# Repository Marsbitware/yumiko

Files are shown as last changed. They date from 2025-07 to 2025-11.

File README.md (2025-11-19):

# Yumiko – Smart AI Camera for Raspberry Pi

Yumiko is an AI-powered camera app for the Raspberry Pi, featuring live preview, AI style transfer, gallery navigation, QR code export, and a fullscreen GUI for touchscreens.  
Designed for Pi 4 with Raspberry Pi Camera v3 and a 3.5" LCD touchscreen.

Yumiko comes from the Japanese yume (夢, “dream”) and -ko (子, “child”), meaning “child of the dream.”
The name reflects the project’s core idea: turning ambitious concepts into a practical and funny tool.

We hope you enjoy using and testing our Project!

<p align="center">
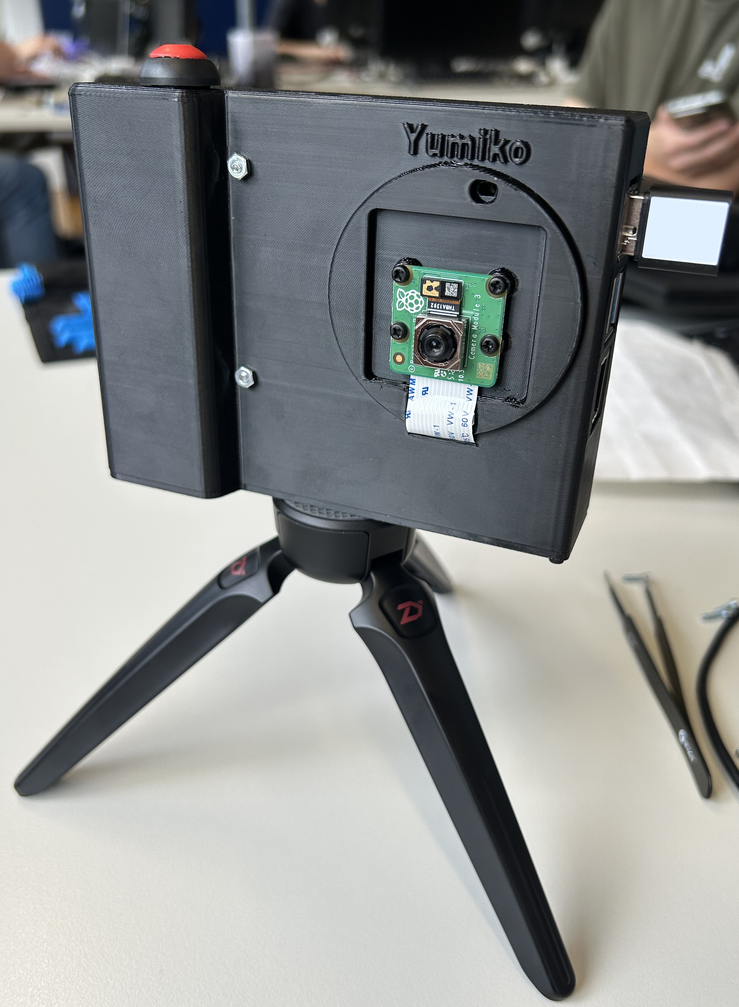
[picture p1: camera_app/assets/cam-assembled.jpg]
Cam assembled
  
</p>

Inspiration:
  - [pi-camera](https://github.com/geerlingguy/pi-camera) by [Jeff Geerling](https://github.com/geerlingguy/)
  - [PIKON Camera](https://www.kevsrobots.com/blog/pikon-camera.html) by [Kevin McAleer](https://www.kevsrobots.com)

---

## Features

- Live camera preview (picamera2)
- AI style transfer (OpenAI API)
- Gallery mode with touch navigation
- Style overlay with GIF loading animation
- QR code for image download
- GPIO button control
- Fullscreen GUI for touchscreens

---

### Directory Structure
```
yumiko/
├── camera_app/
│   ├── camera.py             ← Main application
│   ├── start_camera.sh       ← Start script (for autostart)
│   ├── server.py             ← Start script (for flask-server)
│   ├── assets/
│   │   ├── icons/            ← Gallery, QR, magic wand icons, GIFs, etc.
│   │   ├── styles/           ← Style image buttons
│   │   └── test/             ← Test images or debug material
│   ├── stl_files/            ← stl files for camera case
│   ├── photos/               ← Photos + stylized images
│   └── requirements.txt      ← Python dependencies
├── .gitignore               
├── README.md                 
```

---

## Requirements
- Verified OpenAI account with sufficient funds available and a valid API key
- Raspberry Pi 4 model B (2 GB RAM or better)
- Raspberry Pi Camera v3 (other camera modules should work too)
- 3.5 inch GPIO LCD touchscreen (in our case: Joy-IT model)
- Raspberry Pi OS (Debian Bookworm 64-bit)
- microSD card
- 12mm push button
- 2x4 2.54 mm female headers
- USB-C powerbank and USB-C cable to power the Pi
- Screws and nuts:
    - M2.5 x 12 mm, 4 pcs, each with nut (for Pi)
    - M2.5 x 4 mm screws, 4 pcs (for front camera attachment)
    - M2 x 5 mm screws, 4 pcs (for bottom plate)
- 3D printed case (STL files in the corresponding directory)
- melt-in thread insert: 1/4 Inch 20UNC
- Wireless USB Adapter (in our case: D-Link DWA-131 N300)

---

## 3D-Printed Enclosure

This custom enclosure is based on [Kevin McAleer's](https://www.kevsrobots.com/blog/pikon-camera.html) and [Jeff Geerling’s](https://github.com/geerlingguy/pi-camera) designs and has been modified to better suit the Yumiko build.

### Modifications

Several changes were made to accommodate additional hardware:

- A **12 mm pushbutton** and a **power bank** have been integrated into the case.
- The enclosure was **enlarged along the X and Y axes** to fit the power bank, which slightly exceeds the original dimensions.
- A **reinforced hole** was added to the bottom of the case to support a **melt-in threaded insert** for tripod mounting.
- An additional **access hole** below the battery allows for easy pressing of the power bank’s power button — making Yumiko simple to turn on and off.

### Parts

The enclosure is split into two components:
- `Main_Case.stl`
- `Bottom.stl`

You can find both STL files inside the [`stl_files/`](/camera_app/stl_files) directory.
## Assembly

- Begin by soldering the two leads of the 12mm pushbutton to the first and last pins on one of the 2x4 female headers. (In this setup, one lead connects to a ground pin and the other to GPIO pin 21. Depending on your  configuration, the GPIO pin may vary.)

- Feed the camera module's ribbon cable through the front slit of the enclosure.

- Mount the camera module inside the case using M2.5 x 4mm screws.

- Place the Raspberry Pi into the enclosure so that its ports are aligned with the opening on the left side.

- Secure the Raspberry Pi to the four internal standoffs using M2 x 12mm screws inserted from the outside. Fasten them with nuts on the inside, above the Pi board.

- Connect the ribbon cable from the camera to the Pi’s CSI camera port. Make sure the metal contacts on the ribbon face toward the Pi’s port side.

- Insert the pre-soldered pushbutton header onto the GPIO pins, ensuring that one pin goes to ground and the other to GPIO 21. Carefully bend the wires so they do not press against the display module.

- Attach the Waveshare GPIO TFT display directly onto the Raspberry Pi's GPIO header. It should sit flush on top of the Pi 4 Model B.

- Gently position the camera ribbon cable behind the display to keep everything neat.

- Melt the threaded insert into the bottom plate by using a soldering iron (set to 200–250 °C). Gently heat the insert until it sinks into the hole and fuses with the plastic.

- Finally, secure the bottom cover to the main enclosure using four M2 screws.
---

## Quick Installation

### 1. Flash Raspberry Pi OS

- Use Raspberry Pi Imager to write Raspberry Pi OS 64-bit (Bookworm) to your microSD card.
- Enable SSH and set a username (e.g. `admin`) during flashing.

### 2. First Boot & Basic Setup

```
# Connect via SSH
ssh admin@<IP-address>
```

```
# Update system and install dependencies
sudo apt update
sudo apt install -y python3-pyqt5 python3-opencv libqt5gui5 libqt5widgets5 libqt5core5a libqt5network5 \
    libjpeg-dev libatlas-base-dev git dkms build-essential raspberrypi-kernel-headers hostapd dnsmasq \
    xinput-calibrator
```

### 3. Display Driver

```
git clone https://github.com/goodtft/LCD-show.git
chmod -R 755 LCD-show
cd LCD-show
sudo ./LCD35-show
```
Reboots automatically

To rotate display:
```
cd LCD-show
./rotate.sh 180 #(or 90/270)
```
Also reboots automatically

### 4. Touchscreen Calibration

This step will only be necessary if your touch input is inverted.
```
sudo rm /etc/X11/xorg.conf.d/99-calibration.conf
sudo nano /etc/X11/xorg.conf.d/99-calibration.conf
```
Insert:
```
Section "InputClass"
    Identifier      "calibration"
    MatchProduct    "ADS7846 Touchscreen"
    Option  "Calibration"   "220 3942 3888 200"
    Option  "SwapAxes"      "1"
    Option  "TransformationMatrix" "0 -1 1 -1 0 1 0 0 1"
EndSection
```
Then:
```
# (Optional) Enable VNC
sudo raspi-config  # Interface Options → VNC → Enable
```
```
sudo reboot
```

### 5. Camera Setup

- Connect the camera as per manufacturer instructions.
- Test with:
```
export DISPLAY=:0
libcamera-hello -t 0 --autofocus-mode continuous --qt-preview
```

### 6. Clone & Install Yumiko

```
git clone https://github.com/Marsbitware/yumiko.git
cd yumiko/camera_app/
python3 -m venv venv --system-site-packages
source venv/bin/activate
pip install --upgrade pip
pip install -r requirements.txt
```

### 7. Configure OpenAI API Key

```
nano ~/yumiko/camera_app/.env
```
Add:
```
OPENAI_API_KEY=<your_api_key>
```

### 8. Make Scripts Executable

```
chmod +x ~/yumiko/camera_app/camera.py ~/yumiko/camera_app/server.py ~/yumiko/camera_app/start_camera.sh
```

### 9. Autostart with systemd

```
sudo nano /etc/systemd/system/start_camera.service
```
Insert:
```
[Unit]
Description=Start Camera App on boot
After=multi-user.target
[Service]
ExecStart=/home/admin/yumiko/camera_app/start_camera.sh
Restart=always
User=admin
Environment=DISPLAY=:0
WorkingDirectory=/home/admin/yumiko/camera_app
[Install]
WantedBy=multi-user.target
```
Then:
```
sudo systemctl enable start_camera.service
sudo reboot
```

---

## 10. Hotspot Setup

### Install WiFi Driver

Install WiFi Driver according to your WiFi Adapter. In our case:
```
git clone https://github.com/clnhub/rtl8192eu-linux.git
cd rtl8192eu-linux
sudo nano /home/admin/rtl8192eu-linux/Makefile
```
Edit Makefile to this:
```
CONFIG_PLATFORM_I386_PC = n
CONFIG_PLATFORM_ARM_RPI = y
```
Install drivers:
```
cd /home/admin/rtl8192eu-linux
make clean
make
sudo make install
```

### Configure Network
- Reconfigure the network connection used by the Raspberry Pi to access the internet, as we are switching network managers. The hotspot configuration will be handled at a later stage.
- Ensure that you replace "YourSSID" and "YourPassword" with the appropriate credentials.
- Note: It's easier if you assign a static IP address to the Pi's wlan0 interface on the router.

Connect your Pi to WiFi (Multiple WiFis are possible, you can prioritize them with 
sudo nmcli connection modify SSID1 connection.autoconnect-priority 10
sudo nmcli connection modify SSID2 connection.autoconnect-priority 5
the higher the number, the higher the priority)
```
sudo nmcli dev wifi connect "YourSSID" password "YourPassword" ifname wlan0
```

Make sure the NetworkManager only manages wlan0:
```
sudo nano /etc/NetworkManager/conf.d/unmanaged-wlan1.conf
```

and insert
```
[keyfile]
unmanaged-devices=interface-name:wlan1
```

Configure  hostapd
```
sudo nano /etc/hostapd/hostapd.conf
```

and insert:
```
interface=wlan1
driver=nl80211
ssid=YumikoCam
hw_mode=g
channel=6
wmm_enabled=0
auth_algs=1
ignore_broadcast_ssid=0
wpa=2
wpa_passphrase=yumiko123
wpa_key_mgmt=WPA-PSK
rsn_pairwise=CCMP
```

Configure and move dnsmasq:
```
sudo mv /etc/dnsmasq.conf /etc/dnsmasq.conf.orig
sudo nano /etc/dnsmasq.conf
```

and insert:
```
interface=wlan1
dhcp-range=192.168.50.10,192.168.50.100,1h
domain-needed
bogus-priv
```

Tell the daemon where the hostapd config is:
```
sudo sed -i 's|^#DAEMON_CONF=.*|DAEMON_CONF="/etc/hostapd/hostapd.conf"|' /etc/default/hostapd
```

```
sudo systemctl unmask hostapd
sudo systemctl enable hostapd
sudo systemctl restart hostapd
```

Configure wlan1
```
sudo nano /etc/systemd/network/wlan1.network
```

and insert:
```
[Match]
Name=wlan1

[Network]
Address=192.168.50.1/24
DHCPServer=no
```

Restart everything:
```
sudo systemctl enable systemd-networkd
sudo systemctl restart systemd-networkd
sudo systemctl restart hostapd
sudo systemctl restart dnsmasq
```

Ensure that dnsmasq starts only after hostapd has successfully launched:
```
sudo mkdir -p /etc/systemd/system/dnsmasq.service.d
sudo nano /etc/systemd/system/dnsmasq.service.d/override.conf
```

and insert:
```
[Unit]
After=hostapd.service
Requires=hostapd.service
```

and restart
```
sudo systemctl daemon-reexec
sudo systemctl daemon-reload
sudo systemctl restart dnsmasq
```

### Additional notes
- We recommend creating a QR Code for easy access to the Raspi-Hotspot
- Gallery and style assets are located in ~/yumiko/assets/
- Photos and stylized images are saved in ~/yumiko/camera_app/photos/
- If you are using a different user than admin, make sure to update all relevant paths and usernames in the code and scripts accordingly. This includes things like:
```
File paths (e.g., /home/admin/...)

Systemd service configuration (User=admin)

Virtual environment locations (/home/admin/yumiko/...)

#Failing to update these may cause the application to break or not start properly.
```

---

### Third-Party Assets
Icons used in this project are mostly licensed under the MIT License.  
Source and attribution details:
- [Icon: Arrow](https://www.iconfinder.com/icons/211607/right_arrow_icon)
- [Icon: Magic Wand](https://www.iconfinder.com/icons/9025834/magic_wand_icon)
- [Icon: QR Code](https://www.iconfinder.com/icons/4243314/ux_code_app_qr_icon)
- [Icon: Galery](https://www.iconfinder.com/icons/4706692/camera_equipment_gallery_photography_picture_icon)
- [Icon: Trashcan](https://www.iconfinder.com/icons/8664938/trash_can_delete_remove_icon)

---

<p align="center">
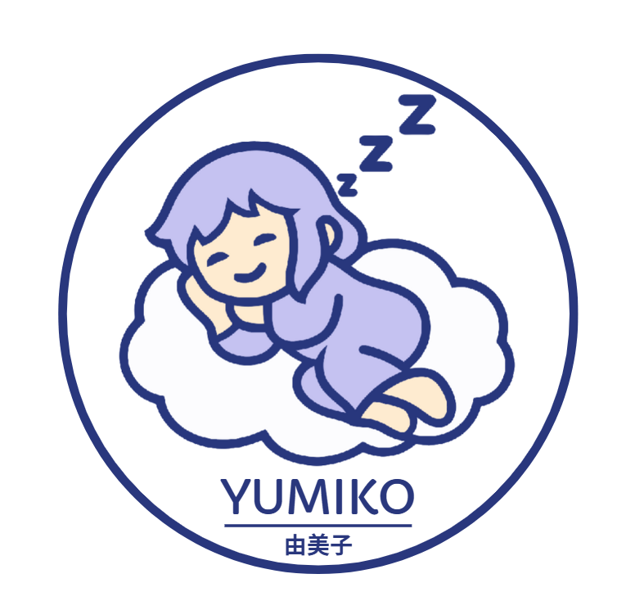
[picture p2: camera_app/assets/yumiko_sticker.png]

</p>

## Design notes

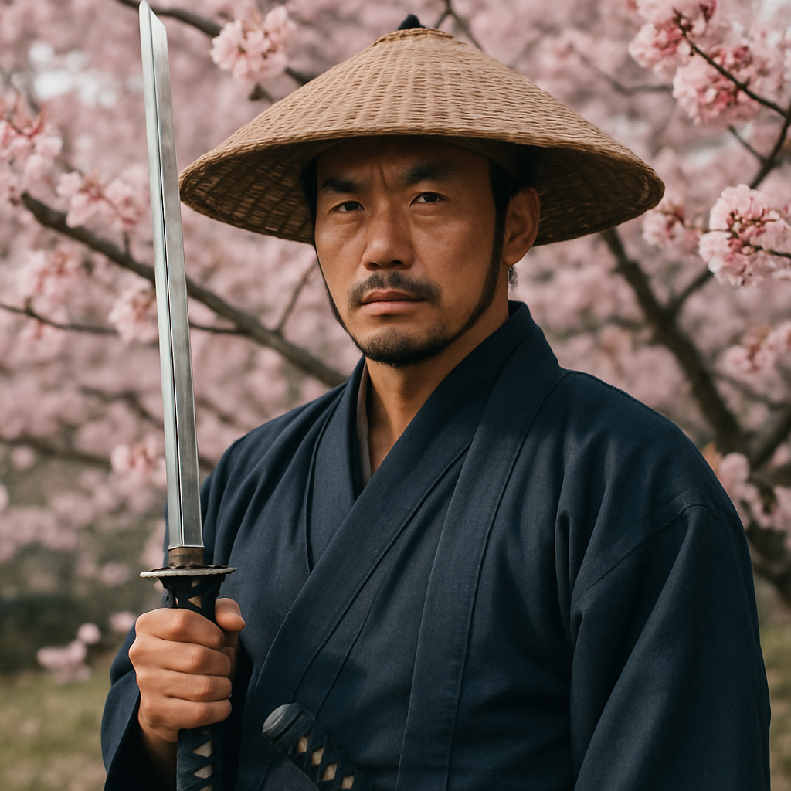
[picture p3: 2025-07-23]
camera_app/assets/styles/samurai.png

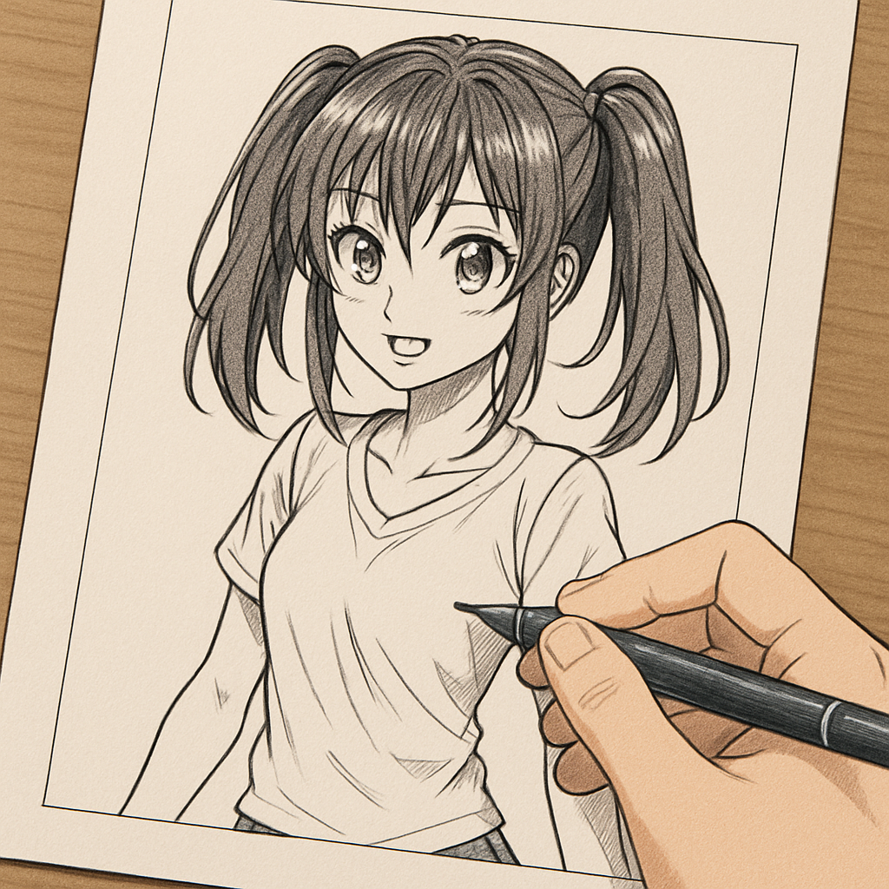
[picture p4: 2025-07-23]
camera_app/assets/styles/manga_bw.png

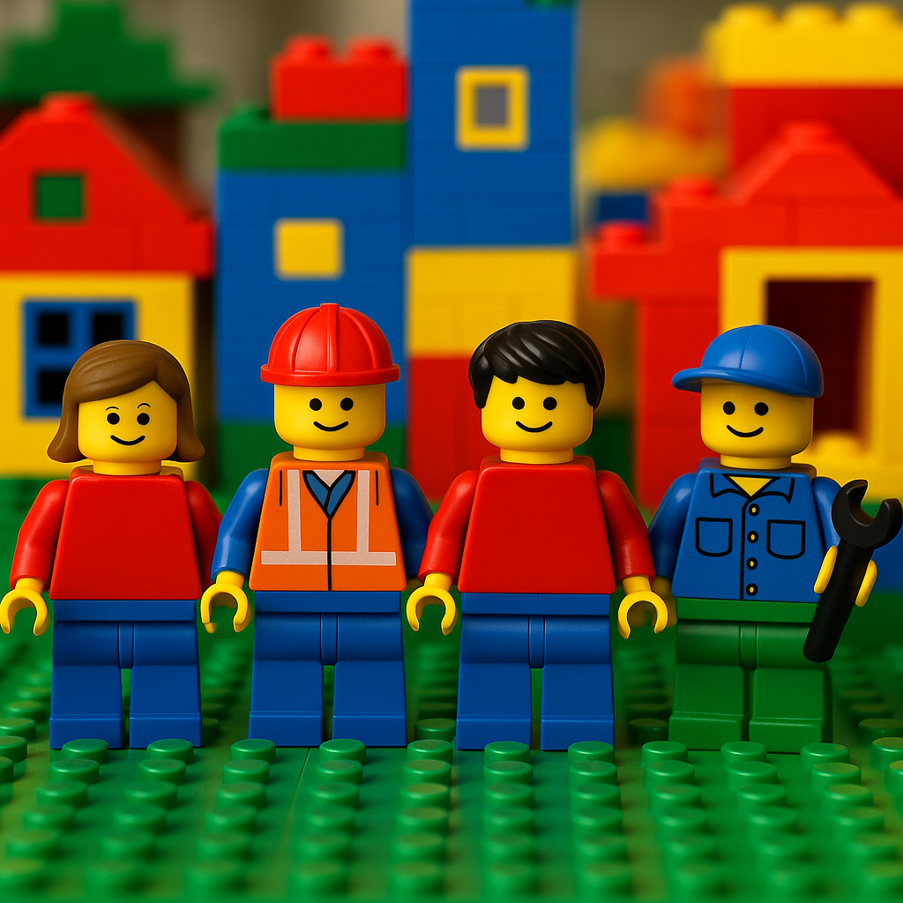
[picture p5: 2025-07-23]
camera_app/assets/styles/lego.png

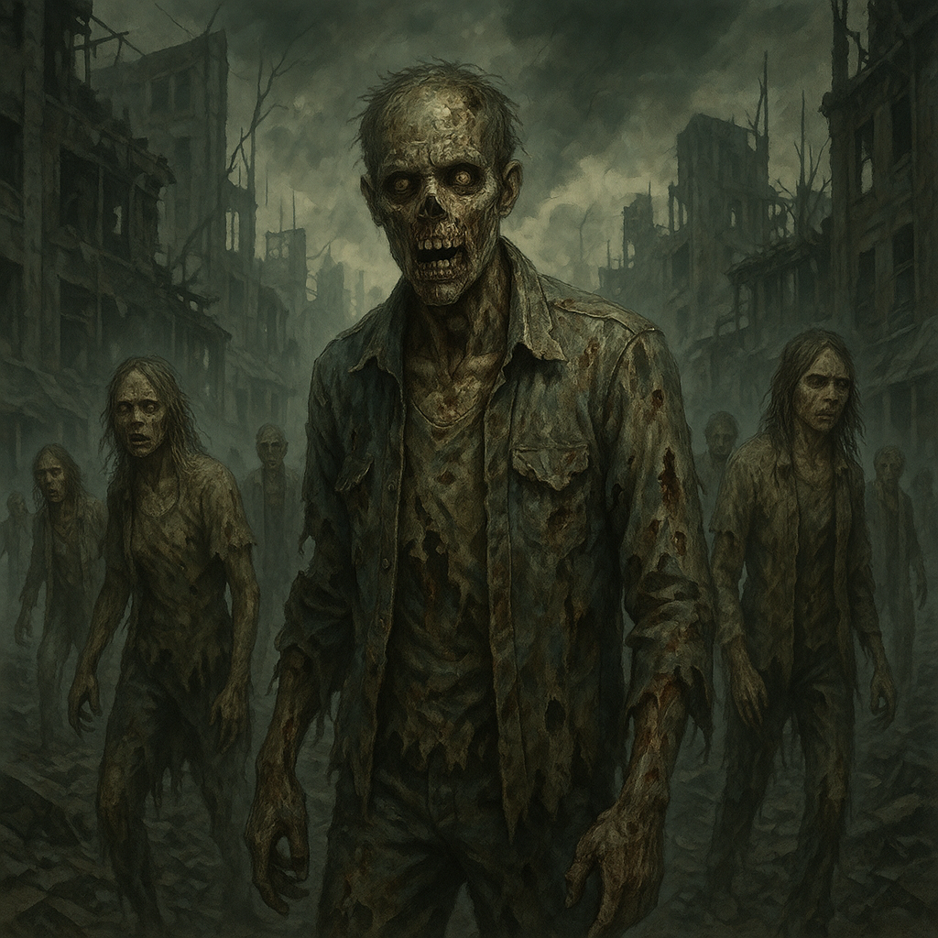
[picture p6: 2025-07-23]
camera_app/assets/styles/zombies.png

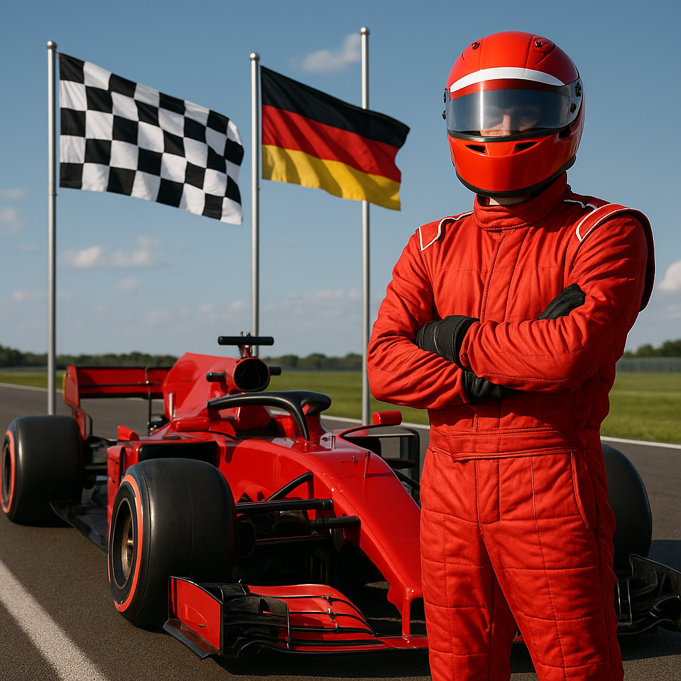
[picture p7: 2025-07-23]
camera_app/assets/styles/formula_1.png

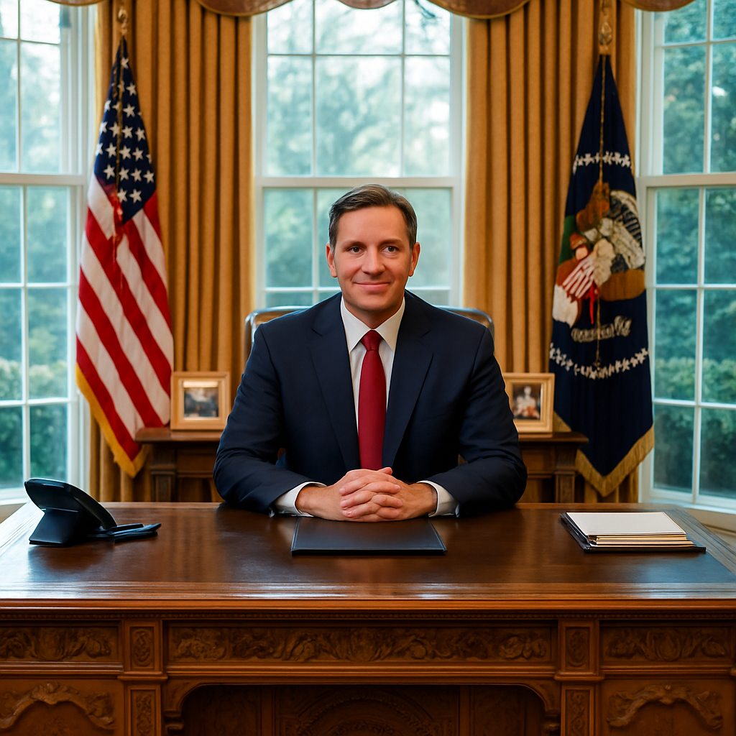
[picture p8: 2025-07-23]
camera_app/assets/styles/oval_office.png

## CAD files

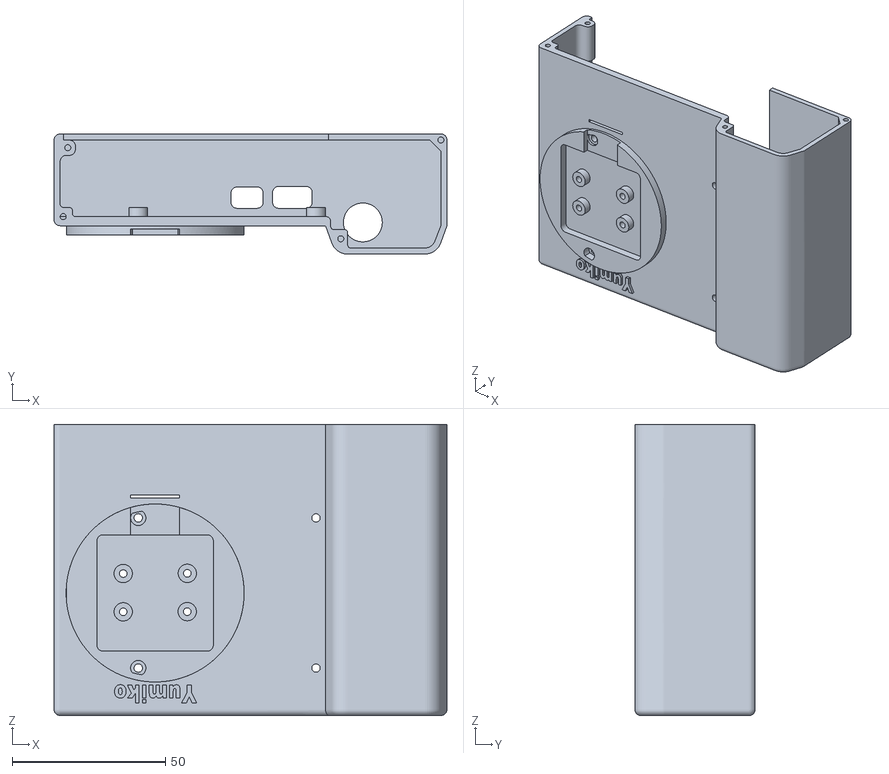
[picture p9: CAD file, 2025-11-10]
camera_app/stl_files/Main_Case.stl
128.2 x 39.2 x 95.0

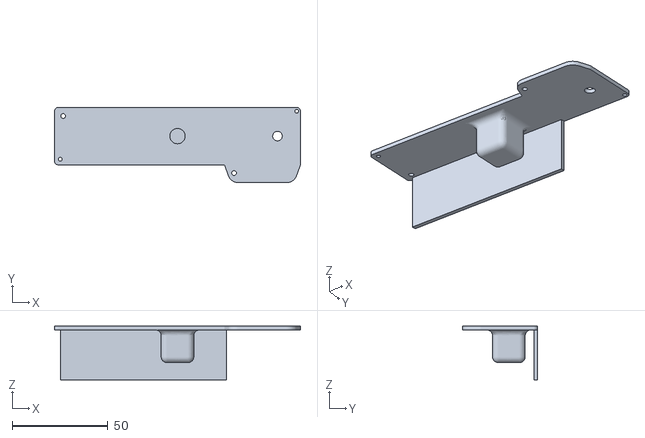
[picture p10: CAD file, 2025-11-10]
camera_app/stl_files/Bottom.stl
128.2 x 39.2 x 28.0

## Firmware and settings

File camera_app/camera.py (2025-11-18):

import os
import sys
import cv2
import time
import shutil
import base64
import requests
import random
import io
import qrcode
import RPi.GPIO as GPIO
from dotenv import load_dotenv
from PIL import Image
from picamera2 import Picamera2
from PyQt5.QtWidgets import (
    QApplication, QLabel, QPushButton, QVBoxLayout, QHBoxLayout, QWidget, QSizePolicy,
    QStackedLayout, QToolButton, QGridLayout
)
from PyQt5.QtCore import (
    Qt, QSize, QRect, QTimer, QRunnable, QThreadPool, pyqtSlot, pyqtSignal, QObject
)
from PyQt5.QtGui import QImage, QPixmap, QIcon, QTransform, QMovie
from openai import OpenAI
from PyQt5.QtGui import QImage, QPixmap
from PyQt5.QtCore import Qt
from functools import partial

# Paths
BASE_DIR = os.path.dirname(os.path.abspath(__file__))
ASSETS_DIR = os.path.join(BASE_DIR, "assets")
PHOTOS_DIR = os.path.join(BASE_DIR, "photos")
STYLE_DIR = os.path.join(ASSETS_DIR, "styles")

# Ensure directories exist
os.makedirs(PHOTOS_DIR, exist_ok=True)
os.makedirs(STYLE_DIR, exist_ok=True)

# Icons
ICON_PATHS = {
    "gallery": os.path.join(ASSETS_DIR, "icons", "gallery.png"),
    "arrow": os.path.join(ASSETS_DIR, "icons", "arrow.png"),
    "qr": os.path.join(ASSETS_DIR, "icons", "qr_code.png"),
    "wand": os.path.join(ASSETS_DIR, "icons", "magic_wand.png"),
    "trash": os.path.join(ASSETS_DIR, "icons", "trash_can.png"),
}

# OpenAI setup
load_dotenv()
api_key = os.getenv("OPENAI_API_KEY")
client = OpenAI(api_key=api_key)

STYLE_PROMPTS = {
        "zombies": (
            "Transform this image into a post-apocalyptic zombie scene. Turn people into zombies or survivors with torn clothing, decayed skin, "
            "and place them in a ruined, post-apocaliptic world with destruction and lurking undead. Make it realistic but don't make the picture too dark"
        ),

        "lego": (
            "Transform this image so that all people, objects, and surroundings appear like the colorful, modular LEGO style. "
            "Use plastic textures, blocky shapes, and bright, toy-like colors typical of a LEGO world."
        ),

        "simpsons": (
            "Transform this image into a cartoon universe like that of The Simpsons. Use flat, saturated colors, thick black outlines, "
            "and exaggerated facial features. Convert characters into yellow-skinned, 2D cartoon figures."
        ),

        "studio_ghibli": (
            "Turn this photo into a Ghibli scene, preserving the original features but transforming the people and the landscape into "
            "classic Ghibli Style."
        ),

        "cyberpunk": (
            "Transform this image into a futuristic cyberpunk scene. Use neon lights, dark cityscapes, holograms, and high-tech fashion. "
            "Incorporate cybernetic enhancements and a gritty, dystopian atmosphere."
        ),

        "renaissance": (
            "Transform this image so that the people and their clothes, objects, and background are reimagined in the style of a Renaissance painting. "
            "Use soft light, realistic proportions, and detailed shading to mimic the classical atmosphere."
        ),

        "mafiosi": (
            "Transform this image into a 1920s–1940s mafia scene, keeping the people and composition intact. Dress everyone in period-accurate suits, "
            "fedoras, and overcoats, and add subtle noir tones and era-specific ambiance. Don't make the picture too dark though. "
        ),

        "oval_office": (
            "Place this scene in the Oval Office while preserving the people and their facial features. Add presidential elements, formal suits, U.S. flags, "
            ", and iconic White House / Oval Office styling."
        ),

        "roman_empire": (
            "Transform this image into the world of Ancient Rome. Dress people Roman military gear, while preserving facial features. "
            "Include things like marble columns, grand statues, or just classical Roman architecture in general. "
        ),

        "samurai": (
            "Transform this image into the world of feudal Japan. Dress people in traditional samurai armor while preserving original features like face or pose. "
            " Include things like katana swords, temples, or misty mountain landscapes with a historical Japanese aesthetic. Also add a little cherry blossom. "
        ),

        "manga_bw": (
            "Transform this image into a black-and-white manga drawing. Use clean ink lines, strong contrast, cross-hatching, while preserving original features, "
            "like face or pose of the people. Focus on dynamic composition and emotional intensity typical of Japanese manga art."
        ),

        "van_gogh": (
            "Transform this image so that people, objects, and the background resemble the style of Vincent van Gogh. Use thick brush strokes, "
            "vibrant contrasting colors, and swirling, expressive textures to mimic his iconic post-impressionist paintings."
        ),

        "medieval": (
            "Transform this image into a piece of naive medieval art. Preserve the original faces and poses, but depict everything in the style "
            "of medieval marginalia and early bestiary illustrations: flat perspective, awkward proportions, humorous misinterpretations of anatomy, "
            "and richly colored illuminated manuscript details with gold-leaf accents on parchment."
        ),

        "horror": (
            "Transform this photo into a dark, fear-inducing horror setting. Retain the recognizable subjects and arrangement, but surround them with eerie shadows, "
            "unsettling atmosphere, and a well-known horror villain. The people are supposed to look afraid but try to preserve facial features and of the people. "
            " Don't make it too dark though. It should still be recognizable. You are allowed to change the pose of the people to make them look scared though. "
        ),

        "formula_1": (
            "Transform this image into a Formula 1 racing theme. Dress people in professional racing suits and helmets, while keeping their facial features (-> open helmets or "
            " helmets being carried) and / or poses. Insert F-1 themed objects like F1-cars, a racetrack, checkered flags, while (more or less) keeping the original composition. "
        ),
    
        "steampunk": (
            "Recreate this image in a detailed steampunk universe. Maintain the people and composition, but dress them in Victorian-inspired outfits enhanced with for example gears, pipes, "
            " goggles, and steam-powered devices. Don't make the picture too dark. "
        ),

        "lord_of_the_rings": (
            "Recreate this image in a high-fantasy medieval world. Keep faces and poses recognizable, but restyle everyone as elegant forest beings, sturdy mountain folk, fierce warrior tribes, "
            " or noble ranger-like characters in detailed fantasy attire. Include a distinctive fantasy landmark—such as a towering fortress, a mystical valley city, or a distant volcanic "
            " stronghold—and surround them with bright, vibrant landscapes. "
        ),

        "minecraft": (
            "Transform this image into the pixelated, blocky world of Minecraft. Convert people, objects, and background into cubic shapes with simple textures. "
            "Use bright, low-resolution graphics and game-like environments with trees, mountains, or structures made from blocks."
        ),

        "donald_duck": (
            "Transform this image into a cartoon world like Donald Duck. Convert people into anthropomorphic, expressive characters with beak-like faces, "
            "cartoon eyes, and colorful, animated surroundings inspired by classic Disney comic and TV styles."
        ),

        "cavemen": (
            "Turn this image into a prehistoric cave tableau. Maintain the original people’s features and layout, dress them in fur or leather outfits, "
            " scatter stone-age tools around, and use a bright, atmospheric cave interior rather than dark shadows. "
        ),

        "star_wars": (
            "Convert this photo into a cinematic sci-fi fantasy scene. Preserve facial features and composition, style people with futuristic robes, armor, "
            " or alien traits, and include glowing energy blades, robotic assistants, starships, and epic galactic environments. "
        )
}


BUTTON_STYLE = """
    QPushButton, QToolButton {
        background-color: rgba(255, 255, 255, 40);
        border: 2px solid black;
        border-radius: 6px;
    }
    QPushButton:hover, QToolButton:hover {
        background-color: rgba(255, 255, 255, 60);
    }
    QPushButton:pressed, QToolButton:pressed {
        background-color: rgba(255, 255, 255, 100);
    }
"""

class WorkerSignals(QObject):
    finished = pyqtSignal(bytes, str, str)

class StyleTransferTask(QRunnable):
    def __init__(self, image_path, style_name):
        super().__init__()
        self.image_path = image_path
        self.style_name = style_name
        self.signals = WorkerSignals()

    def run(self):
        try:
            with open(self.image_path, "rb") as image_file:
                full_prompt = f"Transform this image into the style of {STYLE_PROMPTS.get(self.style_name, '')}"
                response = client.images.edit(
                    model="gpt-image-1",
                    image=[image_file],
                    prompt=full_prompt,
                    n=1,
                    quality="high",
                    size="1024x1024",
                )
                data = response.data[0].b64_json
                if not data:
                    self.signals.finished.emit(None, "No image data received", self.style_name)
                    return
                self.signals.finished.emit(base64.b64decode(data), None, self.style_name)
        except Exception as e:
            self.signals.finished.emit(None, str(e), self.style_name)

FLASK_SERVER = "http://192.168.50.1:5000"

class CameraApp(QWidget):
    gpio_button_pressed = pyqtSignal()

    def __init__(self):
        super().__init__()
        self.styles_per_page = 6
        self.setWindowFlags(Qt.FramelessWindowHint)
        self.setGeometry(0, 0, 480, 320)
        self.setWindowTitle("Smart Camera")
        self.showFullScreen()
        
        self.loading_overlay = None
        self.current_mode = "camera"
        self.image_paths = []
        self.current_index = 0

        self.setup_ui()
        self.setup_camera()
        self.setup_gpio()

    def setup_ui(self):
        self.stack = QStackedLayout()
        self.camera_widget = QWidget()
        self.gallery_widget = QWidget()
        self.label = QLabel()
        self.label.setAlignment(Qt.AlignCenter)
        self.label.setSizePolicy(QSizePolicy.Expanding, QSizePolicy.Expanding)
        self.label.setStyleSheet("background-color: black;")

        camera_layout = QVBoxLayout(self.camera_widget)
        camera_layout.setContentsMargins(0, 0, 0, 0)
        camera_layout.addWidget(self.label)

        self.stack.addWidget(self.camera_widget)
        self.stack.addWidget(self.gallery_widget)

        layout = QVBoxLayout(self)
        layout.setContentsMargins(0, 0, 0, 0)
        layout.addLayout(self.stack)

        self.gallery_button = QPushButton()
        self.gallery_button.setIcon(QIcon(QPixmap(ICON_PATHS["gallery"]).transformed(QTransform().rotate(-90))))
        self.gallery_button.setIconSize(QSize(96, 96))
        self.gallery_button.setFixedSize(120, 120)
        self.gallery_button.setStyleSheet(BUTTON_STYLE)
        self.gallery_button.move(0, 200)
        self.gallery_button.setParent(self.camera_widget)
        self.gallery_button.clicked.connect(self.open_gallery)

        self.loading_label = QLabel(self, alignment=Qt.AlignCenter)
        self.loading_label.setGeometry(0, 0, 480, 320)
        self.loading_label.setStyleSheet("background-color: rgba(0, 0, 0, 180); color: white; font-size: 18px;")
        self.loading_label.setText("Applying style... Please wait.")
        self.loading_label.hide()

    def setup_camera(self):
        self.picam2 = Picamera2()
        self.picam2.configure(self.picam2.create_preview_configuration(
            main={"format": "RGB888", "size": (480, 320)}))
        self.picam2.start()

        self.timer = QTimer()
        self.timer.timeout.connect(self.update_preview)
        self.timer.start(30)

    def setup_gpio(self):
        self.gpio_button_pressed.connect(self.handle_back_or_photo)
        GPIO.setmode(GPIO.BCM)
        GPIO.setup(21, GPIO.IN, pull_up_down=GPIO.PUD_UP)
        GPIO.add_event_detect(21, GPIO.FALLING, callback=self.handle_gpio_press, bouncetime=300)

    def handle_gpio_press(self, channel):
        print("[BUTTON] GPIO 21 pressed")
        self.gpio_button_pressed.emit()

    def handle_back_or_photo(self):
        print(f"[BUTTON] Current mode: {self.current_mode}")
        if self.current_mode == "style_overlay":
            self.open_gallery()
        elif self.current_mode == "qr_overlay":
            if hasattr(self, "qr_overlay") and self.qr_overlay is not None:
                self.qr_overlay.deleteLater()
                self.qr_overlay = None
            self.open_gallery()
        elif self.current_mode == "gallery":
            self.return_to_camera()
        elif self.current_mode == "camera":
            self.take_photo()

    def keyPressEvent(self, event):
        if event.key() == Qt.Key_Escape:
            print("[KEY] ESC pressed")
            if self.current_mode in ["gallery", "qr_overlay", "style_overlay"]:
                self.return_to_camera()

    def update_preview(self):
        frame = self.picam2.capture_array()
        frame = cv2.cvtColor(frame, cv2.COLOR_BGR2RGB)
        h, w, ch = frame.shape

        # Crop to 3:2 aspect ratio (480x320)
        target_aspect = 480 / 320
        frame_aspect = w / h

        if frame_aspect > target_aspect:
            # Image is too wide, crop left/right
            new_w = int(h * target_aspect)
            x1 = (w - new_w) // 2
            frame = frame[:, x1:x1+new_w]
            w = new_w
        else:
            # Image is too tall, crop top/bottom
            new_h = int(w / target_aspect)
            y1 = (h - new_h) // 2
            frame = frame[y1:y1+new_h, :]
            h = new_h

        bytes_per_line = ch * w
        qt_image = QImage(frame.data, w, h, bytes_per_line, QImage.Format_RGB888)
        pixmap = QPixmap.fromImage(qt_image)
        self.label.setPixmap(pixmap.scaled(480, 320, Qt.IgnoreAspectRatio, Qt.SmoothTransformation))

    def open_gallery(self):
        print("[INFO] Opening gallery")
        files = [
            os.path.join(PHOTOS_DIR, f)
            for f in os.listdir(PHOTOS_DIR)
            if f.lower().endswith((".jpg", ".png"))
        ]
        self.image_paths = sorted(files, key=os.path.getmtime, reverse=True)
        if self.image_paths:
            self.current_index = 0
            self.show_current_image()
            self.stack.setCurrentWidget(self.gallery_widget)
        self.current_mode = "gallery"

    def return_to_camera(self):
        print("[INFO] Returning to camera mode")
        self.stack.setCurrentWidget(self.camera_widget)
        self.current_mode = "camera"

    def take_photo(self):
        print("[PHOTO] Taking photo")
        self.picam2.stop()
        still_config = self.picam2.create_still_configuration(main={"format": "RGB888", "size": (2028, 1520)})
        self.picam2.configure(still_config)
        self.picam2.start()
        frame = self.picam2.capture_array()

        preview_config = self.picam2.create_preview_configuration(main={"format": "RGB888", "size": (480, 320)})
        self.picam2.stop()
        self.picam2.configure(preview_config)
        self.picam2.start()

        h, w, _ = frame.shape
        crop_size = min(w, h)
        x1 = (w - crop_size) // 2
        y1 = (h - crop_size) // 2
        shift = int(0.10 * crop_size)
        x1 = max(0, x1 - shift)

        cropped = frame[y1:y1 + crop_size, x1:x1 + crop_size]

        filename = f"photo_{int(time.time())}.png"
        filepath = os.path.join(PHOTOS_DIR, filename)
        cv2.imwrite(filepath, cropped)
        print(f"[PHOTO] Saved to: {filepath}")
        self.flash_screen()

    def flash_screen(self):
        flash = QLabel(self.camera_widget)
        flash.setStyleSheet("background-color: white;")
        flash.setGeometry(0, 0, 480, 320)
        flash.show()
        flash.raise_()
        QTimer.singleShot(100, flash.deleteLater)

    def show_current_image(self):
        self.clear_gallery_widget()

        self.gallery_image_label = QLabel(self.gallery_widget)
        self.gallery_image_label.setAlignment(Qt.AlignCenter)
        self.gallery_image_label.setGeometry(0, 0, 480, 320)
        self.gallery_image_label.setStyleSheet("background-color: black;")

        current_path = self.image_paths[self.current_index]
        self.current_image_path = current_path

        pixmap = QPixmap(current_path)
        scaled = pixmap.scaled(480, 320, Qt.KeepAspectRatio, Qt.SmoothTransformation)
        self.gallery_image_label.setPixmap(scaled)
        self.gallery_image_label.show()

        self.create_overlay_buttons()

    def clear_gallery_widget(self):
        for child in self.gallery_widget.findChildren(QWidget):
            child.setParent(None)
            child.deleteLater()

        layout = self.gallery_widget.layout()
        if layout is not None:
            self.clear_nested_layout(layout)

    def clear_nested_layout(self, layout):
        while layout.count():
            item = layout.takeAt(0)
            widget = item.widget()
            if widget is not None:
                widget.setParent(None)
                widget.deleteLater()
            elif item.layout() is not None:
                self.clear_nested_layout(item.layout())
        layout.deleteLater()

    def create_overlay_buttons(self):
        def make_button(icon, pos, callback):
            btn = QToolButton(self.gallery_widget)
            btn.setIcon(QIcon(icon))
            btn.setIconSize(QSize(64, 64))
            btn.setFixedSize(72, 72)
            btn.setStyleSheet(BUTTON_STYLE)
            btn.move(*pos)
            btn.clicked.connect(callback)
            btn.raise_()
            btn.show()

        # ← Left arrow
        left_icon = QPixmap(ICON_PATHS["arrow"]).transformed(QTransform().scale(-1, 1))
        btn_left = QToolButton(self.gallery_widget)
        btn_left.setIcon(QIcon(left_icon))
        btn_left.setIconSize(QSize(96, 96))
        btn_left.setFixedSize(120, 120)
        btn_left.setStyleSheet(BUTTON_STYLE)
        btn_left.move(0, 100)
        btn_left.clicked.connect(self.show_previous_image)
        btn_left.raise_()
        btn_left.show()

        # → Right arrow
        btn_right = QToolButton(self.gallery_widget)
        btn_right.setIcon(QIcon(ICON_PATHS["arrow"]))
        btn_right.setIconSize(QSize(96, 96))
        btn_right.setFixedSize(120, 120)
        btn_right.setStyleSheet(BUTTON_STYLE)
        btn_right.move(480 - 120, 100)
        btn_right.clicked.connect(self.show_next_image)
        btn_right.raise_()
        btn_right.show()

        make_button(ICON_PATHS["qr"], (5, 5), self.show_qr_overlay)
        make_button(ICON_PATHS["wand"], (403, 5), self.show_style_overlay)
        make_button(ICON_PATHS["trash"], (403, 243), self.delete_current_image)

    def show_next_image(self):
        if self.current_index < len(self.image_paths) - 1:
            self.current_index += 1
            self.show_current_image()

    def show_previous_image(self):
        if self.current_index > 0:
            self.current_index -= 1
            self.show_current_image()

    def show_qr_overlay(self):
        if not hasattr(self, "current_image_path") or not self.current_image_path:
            print("[QR] No current image found.")
            return

        if hasattr(self, "qr_overlay") and self.qr_overlay is not None:
            self.qr_overlay.deleteLater()
            self.qr_overlay = None

        filename = os.path.basename(self.current_image_path)
        qr_url = f"{FLASK_SERVER}/view/{filename}"

        print(f"[QR] Generating QR for: {qr_url}")
        qr = qrcode.QRCode(border=2, box_size=8)
        qr.add_data(qr_url)
        qr.make(fit=True)
        img = qr.make_image(fill_color="black", back_color="white")

        buf = io.BytesIO()
        img.save(buf, format="PNG")
        qt_img = QImage.fromData(buf.getvalue())

        # Create Overlay
        overlay = QWidget(self)
        overlay.setGeometry(0, 0, self.width(), self.height())
        overlay.setStyleSheet("background-color: rgba(0,0,0,180);")
        overlay.setAttribute(Qt.WA_DeleteOnClose)
        overlay.raise_()

        # Show QR-Code
        qr_label = QLabel(overlay)
        qr_pixmap = QPixmap.fromImage(qt_img).scaled(240, 240, Qt.KeepAspectRatio, Qt.SmoothTransformation)
        qr_label.setPixmap(qr_pixmap)
        qr_label.setGeometry((overlay.width() - 240) // 2, 60, 240, 240)
        qr_label.show()

        # Display Info
        txt = QLabel("📱 Scan the QR code\nto view & download the photo", overlay)
        txt.setStyleSheet("color: white; font-size: 16px; font-weight: bold;")
        txt.setAlignment(Qt.AlignCenter)
        txt.setGeometry((overlay.width() - 300) // 2, 320, 300, 40)
        txt.show()

        overlay.show()

        self.qr_overlay = overlay 
        self.current_mode = "qr_overlay"

    def show_style_overlay(self):
        print("[AI] Showing style overlay")
        if self.current_mode != "style_overlay":
            self.current_style_page = 0

        if hasattr(self, "style_overlay") and self.style_overlay is not None:
            try:
                self.style_overlay.deleteLater()
            except RuntimeError:
                pass
            self.style_overlay = None
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

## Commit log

2025-07-17 Added qr-code function
    -modified camera.py (qr-code function)
    -upload server.py
    -modified start_camera.sh, so that it automaticly starts the flask server
    -Updates in README.md
    -updated requirements.txt
2025-07-17 Update camera.py
    changed #´s from German to English
2025-07-18 Update camera.py
    Updated IP ip for Flask Server in camera.py
2025-07-21 Verschönerungen in der Readme
2025-07-23 Add new style images and enhance style overlay UI
    Added multiple new style images to assets/styles and updated the style selection overlay in camera.py to support paging, random style selection, and improved layout. The README was rewritten for clar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
2025-07-23 Update and expand README with setup and structure details
    Added project inspiration, detailed directory structure, and expanded requirements and assembly sections. Improved and clarified installation, configuration, and hotspot setup instructions, including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
2025-07-24 Update asset paths and ensure directories exist
    Moved VNC instructions in README and updated asset/photo directory paths to reflect new structure under ~/yumiko/. Added directory creation for photos and styles in camera.py to prevent errors if missing. Included notes in README about updating paths and usernames when using a different user.
    [camera.py]
2025-07-24 Crop camera preview to 3:2 aspect ratio and improve layout
    Added logic to crop the camera preview to a 3:2 (480x320) aspect ratio before displaying. Set a black background for the preview label and removed redundant layout code. Also initialized current_style_page in show_style_overlay for consistency.
    (Bug Fix for "Zoom-in Bug")
    [camera.py]
2025-07-24 Refactor style overlay and button handler logic
    Removes duplicate handle_back_or_photo method and ensures style overlay is properly reset before showing. Also replaces lambda with functools.partial for style button connections to improve clarity and reliability.
    [camera.py]
2025-07-25 Update README with stl_files directory and corrections
    Added the stl_files directory to the project structure and updated references to STL file locations. Minor formatting and directory path corrections for clarity.
2025-07-28 Fix overlay cleanup and attribute handling in CameraApp
    Ensures QR and style overlays are properly deleted and set to None before creating new overlays, preventing potential memory leaks and runtime errors. Adds attribute checks and exception handling for overlay deletion.
    [camera.py]
2025-09-11 added cam-assembled.jpg
2025-11-17 Refine style prompts for image transformations
    Updated style prompts for various themes in the camera application. Enhanced descriptions for better clarity and detail.
2025-11-17 Fix formatting issues in camera.py descriptions
    [camera.py]
2025-11-18 Fix typo in zombie scene prompt
    [camera.py]
2025-11-18 Fix typo in touchscreen calibration section
2025-11-19 Update screw count for bottom plate in README
